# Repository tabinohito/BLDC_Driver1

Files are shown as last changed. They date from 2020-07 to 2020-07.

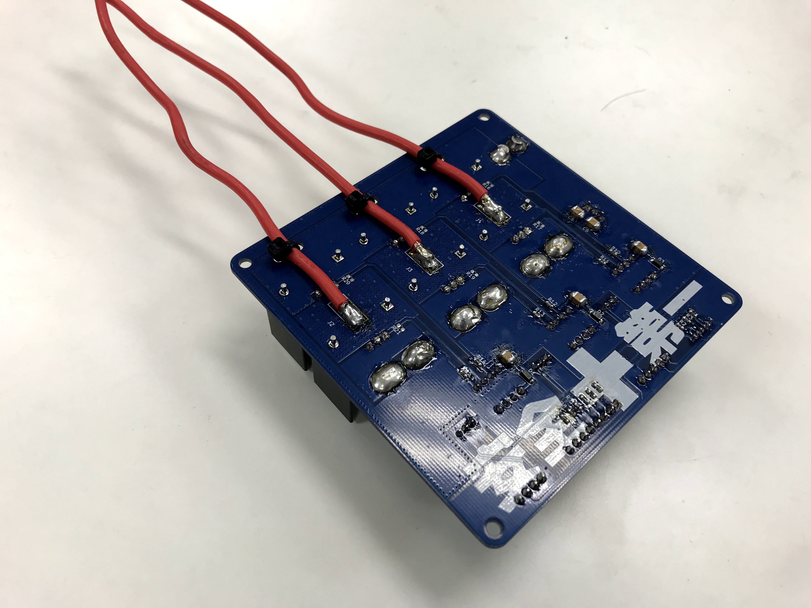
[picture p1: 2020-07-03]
image/Circuit_Image3.JPG

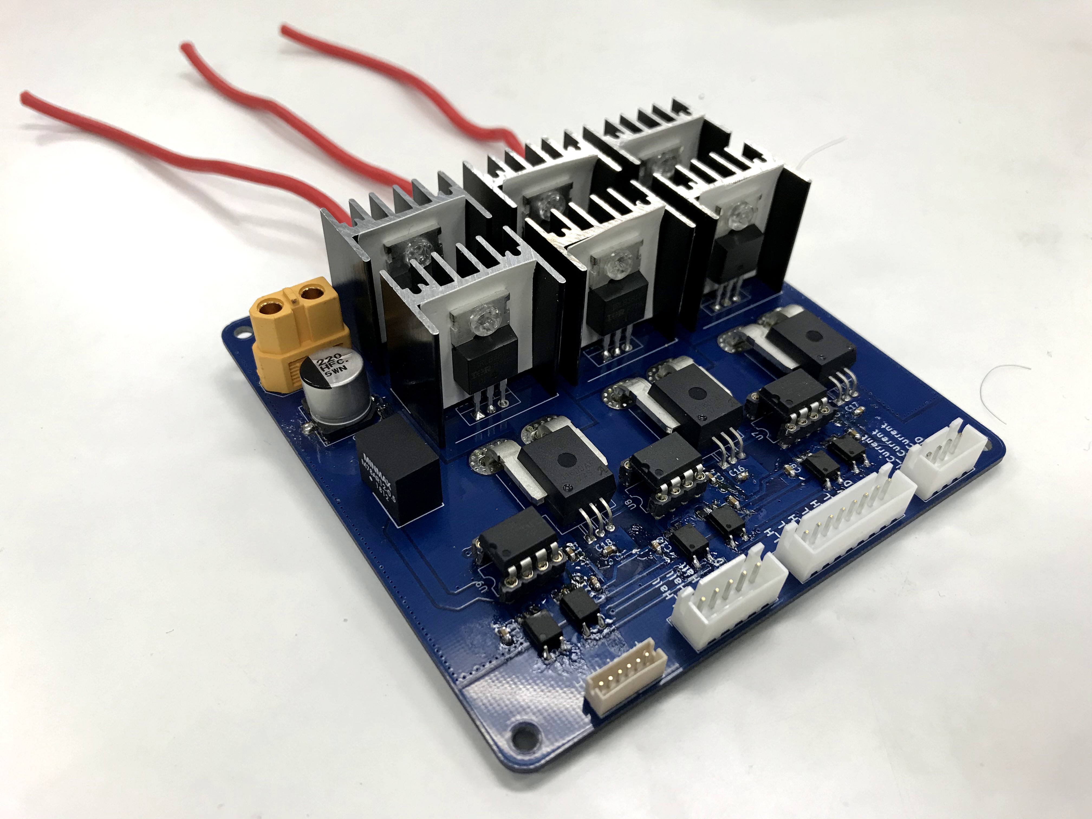
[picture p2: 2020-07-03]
image/Circuit_Image2.JPG

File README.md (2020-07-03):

# BLDC_Driver1
## Review
- とりあえず回ったから、動作的に問題はなさそう
- でも、ACS758LCB-100U-PFF-Tの電流の測定範囲が -100 ~ 100 A で広すぎて分解能が辛い。
- ロックタイトで、ケーブル固定してるのは良き
- IRのゲートドライバが、アイソレートついてなくて辛い

## Parts List(肝心なとこだけ)
- 電流センサ : ACS758LCB-100U-PFF-T
- ゲートドライバ : IR2302
- FET : IRLB3813PBF
- DC-DC : M78AR12-0.5
- ヒートシンク : 幅24x高さ17x奥行25mm
- コネクタ 
  - PWM,CurrentSensor,HallSensor_Output : XHコネクタ　<br>
  - HallSensor_Input : ZHコネクタ <br>
  - Vin : XT60 <br>

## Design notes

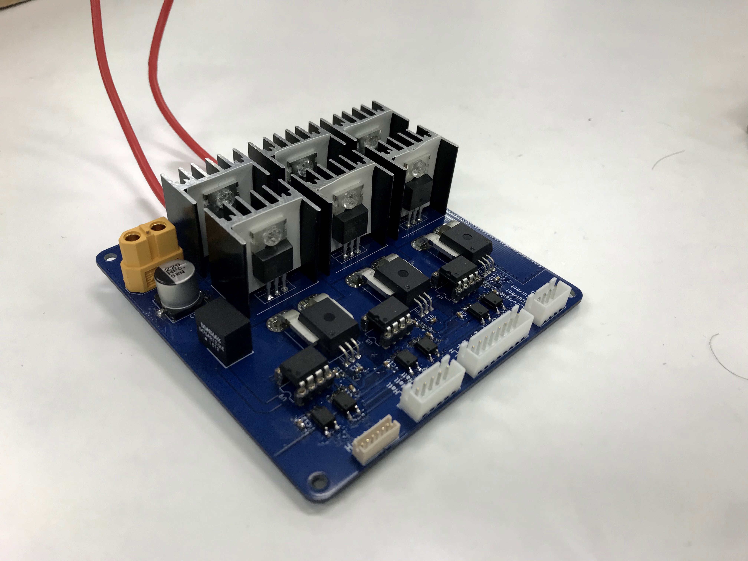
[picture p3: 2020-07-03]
image/Circuit_Image1.JPG

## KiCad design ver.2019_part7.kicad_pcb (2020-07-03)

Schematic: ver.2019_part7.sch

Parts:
C1: 220uF; CP_Elec_10x7.9
C2, C3, C4, C5, C6: 3.3uF; C_1210_3225Metric
C7, C8, C9, C10, C11, C12, C13, C14, C15, C16, C17, C18: 0.1uF; C_0603_1608Metric
D1, D2, D3: D; D_SOD-123
J1: Vin; XT60Conector
J2: U; conecter_1
J3: V; conecter_1
J4: W; conecter_1
J5: Input_Signal; JST_XH_B08B-XH-A_1x08_P2.50mm_Vertical
J6: Current_Sensor; JST_XH_B04B-XH-A_1x04_P2.50mm_Vertical
J7: Hall_Sensor; JST_XH_B05B-XH-A_1x05_P2.50mm_Vertical
J8: Hall_input; SHDR6W50P0X150_1X6_1050X350X450P
MH1, MH2, MH3, MH4, MH5, MH6, MH7, MH8, MH9, MH10: MountingHole; MountingHole_3.2mm_M3
Q1, Q2, Q3, Q4, Q5, Q6: Q_NMOS_GDS; TO-220-3_Vertical
R1, R2, R3: 10k; R_0603_1608Metric
R4, R5, R6, R7, R8, R9: 330; R_0603_1608Metric
R10, R11, R12, R13, R14, R15: 20-100; R_0603_1608Metric
R16, R17, R18, R19, R20, R21: 220k; R_0603_1608Metric
U1, U2, U3, U4, U5, U6: TLP152; SO-6
U7, U8, U9: IR2108; DIP-8_W7.62mm
U10: L7812; SHDR3W75P0X254_1X3_1128X755X1070P
U11, U12, U13: ACS758xCB-100U-PFF; Allegro_CB_PFF
U14: Heatsink_U_H; SHDR2W140P0X1780_1X2_2350X1700X2500P; Manufacturer_Part_Number 17PB024-01025
U15: Heatsink_U_L; SHDR2W140P0X1780_1X2_2350X1700X2500P; Manufacturer_Part_Number 17PB024-01025
U16: Heatsink_V_H; SHDR2W140P0X1780_1X2_2350X1700X2500P; Manufacturer_Part_Number 17PB024-01025
U17: Heatsink_V_L; SHDR2W140P0X1780_1X2_2350X1700X2500P; Manufacturer_Part_Number 17PB024-01025
U18: Heatsink_W_H; SHDR2W140P0X1780_1X2_2350X1700X2500P; Manufacturer_Part_Number 17PB024-01025
U19: Heatsink_W_L; SHDR2W140P0X1780_1X2_2350X1700X2500P; Manufacturer_Part_Number 17PB024-01025

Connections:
+5VL: C16.1, C17.1, C18.1, J5.7, J7.4, J8.6, R1.2, R2.2, R3.2, U11.1 (VCC), U12.1 (VCC), U13.1 (VCC)
+12V: C6.1, C7.1, C8.1, C9.1, C10.1, C11.1, C12.1, C13.1, C14.1, C15.1, D1.2, D2.2, D3.2, U1.6, U2.6, U3.6, U4.6, U5.6, U6.6, U7.1 (VCC), U8.1 (VCC), U9.1 (VCC), U10.3 (OUT)
/U_ADC: J6.1, U11.3 (VIOUT)
/U_Current: Q6.3, R21.1, U11.4 (IP+)
/U_H: R14.2, U7.7 (HO)
/U_Hall: J7.1, J8.2, R3.1
/U_L: R15.2, U7.5 (LO)
/U_Out: C2.2, J2.1, Q5.3, Q6.2, R20.1, U7.6 (VS)
/V_ADC: J6.2, U12.3 (VIOUT)
/V_Current: Q4.3, R19.1, U12.4 (IP+)
/V_H: R12.2, U8.7 (HO)
/V_Hall: J7.2, J8.3, R2.1
/V_L: R13.2, U8.5 (LO)
/V_Out: C3.2, J3.1, Q3.3, Q4.2, R18.1, U8.6 (VS)
/W_ADC: J6.3, U13.3 (VIOUT)
/W_Current: Q2.3, R17.1, U13.4 (IP+)
/W_H: R10.2, U9.7 (HO)
/W_Hall: J7.3, J8.4, R1.1
/W_L: R11.2, U9.5 (LO)
/W_Out: C4.2, J4.1, Q1.3, Q2.2, R16.1, U9.6 (VS)
/input_U_H: J5.1, R4.2
/input_U_L: J5.2, R5.2
/input_V_H: J5.3, R6.2
/input_V_L: J5.4, R7.2
/input_W_H: J5.5, R8.2
/input_W_L: J5.6, R9.2
GND: C16.2, C17.2, C18.2, J5.8, J6.4, J7.5, J8.1, U1.3, U2.3, U3.3, U4.3, U5.3, U6.3, U11.2 (GND), U12.2 (GND), U13.2 (GND)
GNDPWR: C1.2, C5.2, C6.2, C7.2, C8.2, C9.2, C10.2, C11.2, C12.2, C13.2, C14.2, C15.2, J1.1, U1.4, U2.4, U3.4, U4.4, U5.4, U6.4, U7.4 (COM), U8.4 (COM), U9.4 (COM), U10.2 (GND), U11.5 (IP-), U12.5 (IP-), U13.5 (IP-)
unnamed: C2.1, D1.1, U7.8 (VB)
unnamed: C3.1, D2.1, U8.8 (VB)
unnamed: C4.1, D3.1, U9.8 (VB)
unnamed: Q1.1, R10.1, R16.2
unnamed: Q2.1, R11.1, R17.2
unnamed: Q3.1, R12.1, R18.2
unnamed: Q4.1, R13.1, R19.2
unnamed: Q5.1, R14.1, R20.2
unnamed: Q6.1, R15.1, R21.2
unnamed: R4.1, U1.1
unnamed: R5.1, U2.1
unnamed: R6.1, U3.1
unnamed: R7.1, U4.1
unnamed: R8.1, U5.1
unnamed: R9.1, U6.1
unnamed: U1.5, U7.2 (HIN)
unnamed: U2.5, U7.3 (~LIN)
unnamed: U3.5, U8.2 (HIN)
unnamed: U4.5, U8.3 (~LIN)
unnamed: U5.5, U9.2 (HIN)
unnamed: U6.5, U9.3 (~LIN)
VCC: C1.1, C5.1, J1.2, Q1.2, Q3.2, Q5.2, U10.1 (IN)

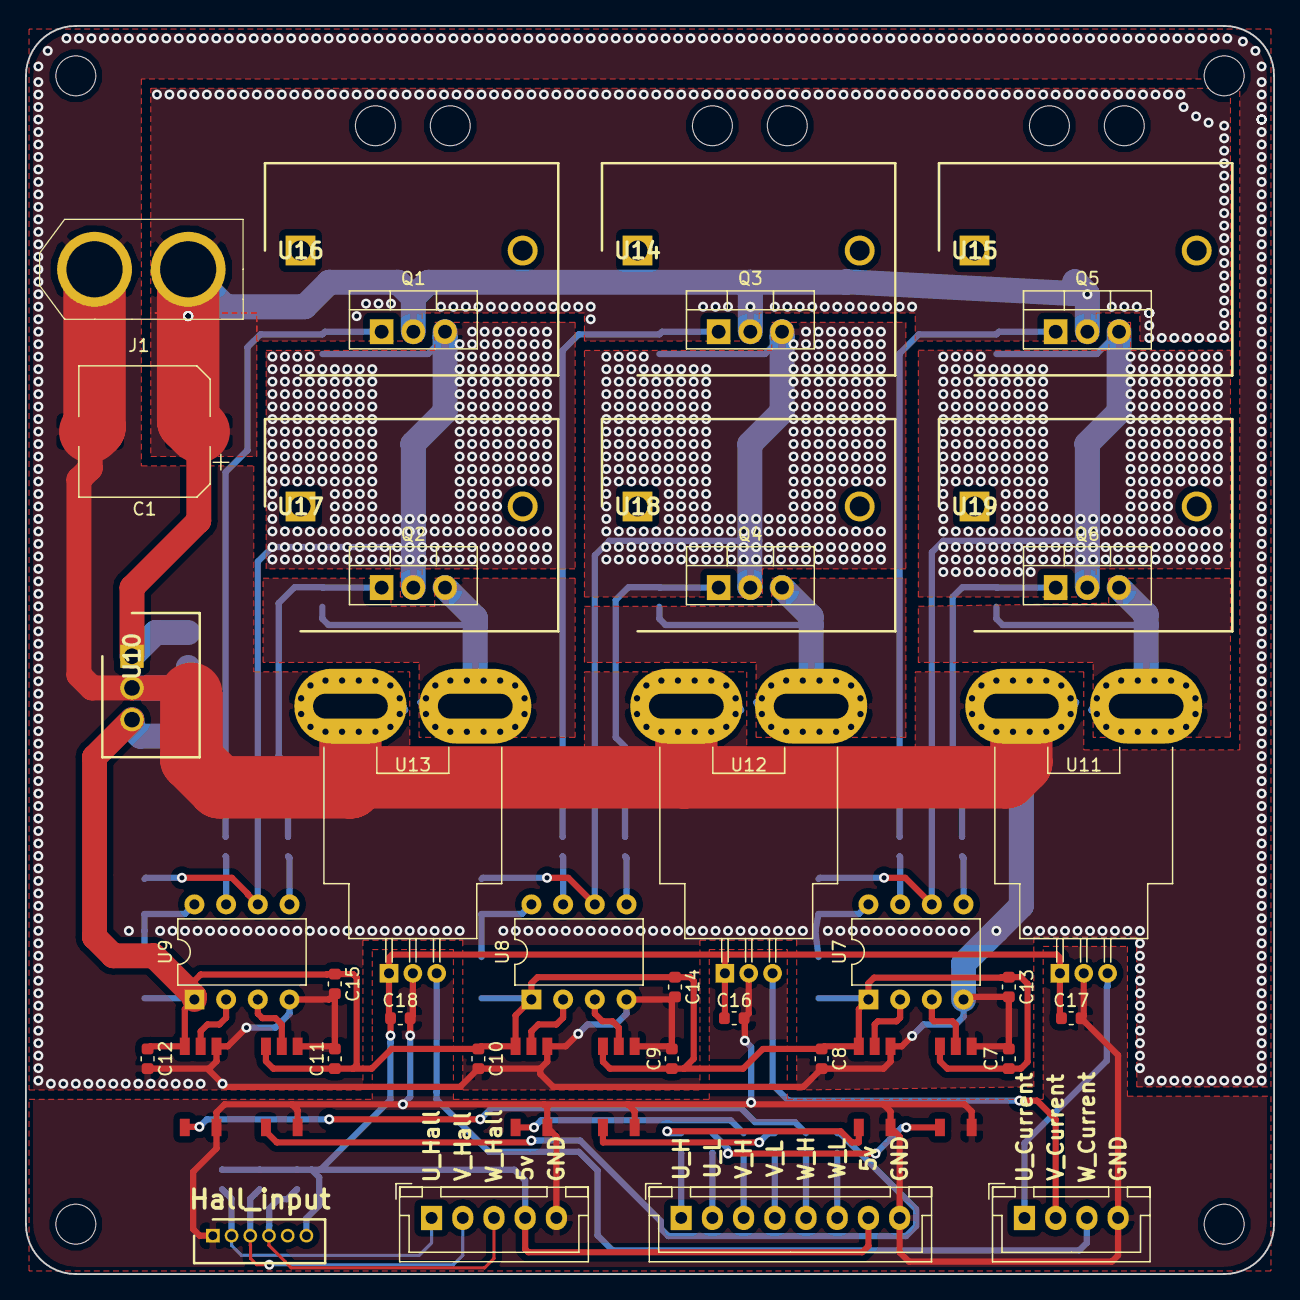
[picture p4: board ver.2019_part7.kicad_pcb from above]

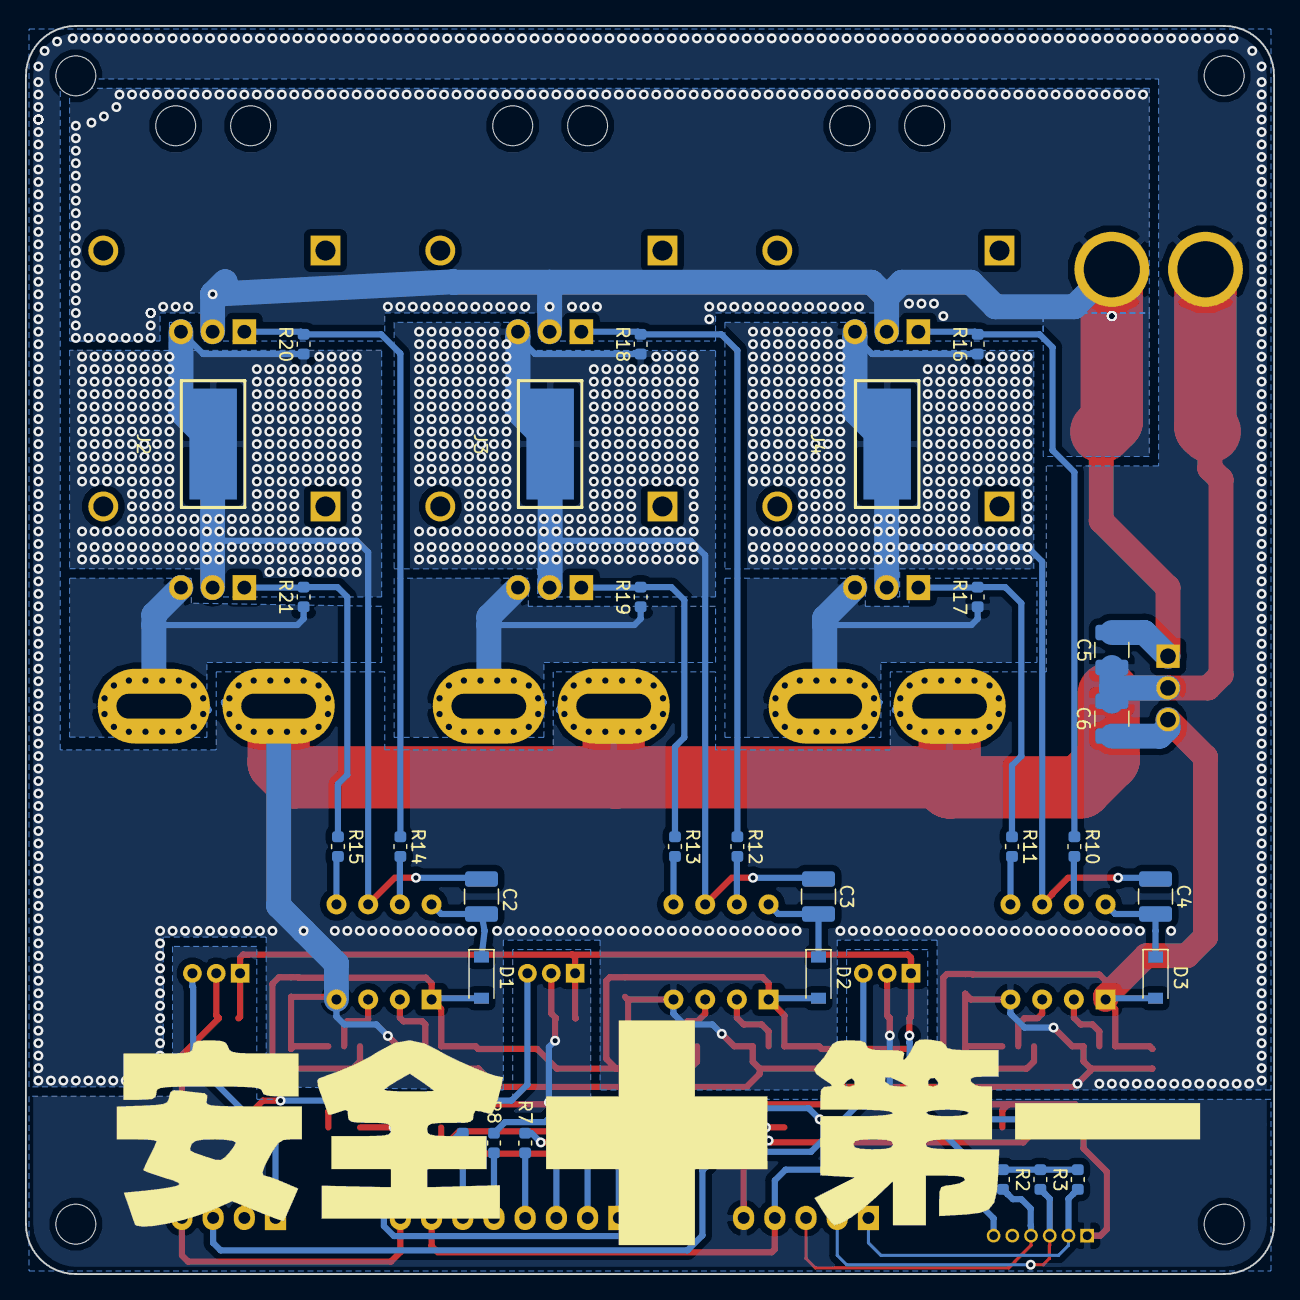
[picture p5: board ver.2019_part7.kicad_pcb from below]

Board: 2 copper layers, 100.0 x 100.0 mm, 85 parts (32 on the bottom side), 50 nets.
